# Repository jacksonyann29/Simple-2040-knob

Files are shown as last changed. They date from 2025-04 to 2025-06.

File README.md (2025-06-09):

# Simple-2040-knob
 PCB Design for a single rotary encoder HID, based on a RP2040 microcontroller.

## About
The goal of this project was to get more practice designing PCBs by implementing a microcontroller directly on a PCB. The current iteration successfully works except for USB programming and communication. USB power works, and programming over the SWD pins also works demonstrating that the RP2040 and flash were correctly configured including the crystal oscillator (at least for the simple led blink code tested on the device).

## Future Changes
*	Shorten the USB traces, use a surface mount usb port and double check impedance so USB communication will work.
*	Replace the crystal circuit with an external crystal oscillator IC which would hopefully be simpler to implement and more robust.
*	Add hardware debouncing to the encoder implementation.

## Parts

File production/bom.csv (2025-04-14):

Designator | Footprint | Quantity | Value | LCSC Part #
C1, C2 | 1206 | 2 | 1uF
C10, C9 | 0805 | 2 | 1uF
C11, C12, C15, C3, C4, C5, C6, C7, C8 | 0603 | 9 | 100n
C13 | 0805 | 1 | 29pF
C14 | 0805 | 1 | 27pF
D1 | D_SOD-123F | 1 | MBR1020VL
D2 | 1206 | 1 | LED_25
D3 | 1206 | 1 | PWR
J1 | GCT_USB4085-GF-A_REVB | 1 | USB4085-GF-A_REVB
J2 | PinHeader_1x03_P2.54mm_Vertical | 1 | DEBUG
MT1 | XDCR_PEC11R-4215F-S0024 | 1 | PEC11R-4215F-S0024
R1 | 1206 | 1 | 1M
R10, R7 | 0603 | 2 | 27.4
R11, R4, R5 | 1206 | 3 | 10k
R12, R13, R14, R15 | 1206 | 4 | 1k
R16, R6 | 1206 | 2 | 470
R2, R3 | 1206 | 2 | 5.1k
R8 | 0603 | 1 | DNP
R9 | 0603 | 1 | 1k
SW1 | SW_PUSH_6mm | 1 | BOOT_SEL
TP1 | TestPoint_Pad_D1.5mm | 1 | RUN
TP2 | TestPoint_Pad_D1.5mm | 1 | 1V1
TP3 | TestPoint_Pad_D1.5mm | 1 | 3V3
TP4 | TestPoint_Pad_D1.5mm | 1 | 5V
TP5 | TestPoint_Pad_D1.5mm | 1 | GND
U1 | SOT95P285X140-5N | 1 | AP2112K-3.3TRG1
U2 | QFN40P700X700X90-57N | 1 | SC0914_13_
U3 | SOIC-8_5.23x5.23mm_P1.27mm | 1 | W25Q16JVSS
Y1 | XTAL_ABLS7M-12.000MHZ-B-2-T | 1 | 12MHz

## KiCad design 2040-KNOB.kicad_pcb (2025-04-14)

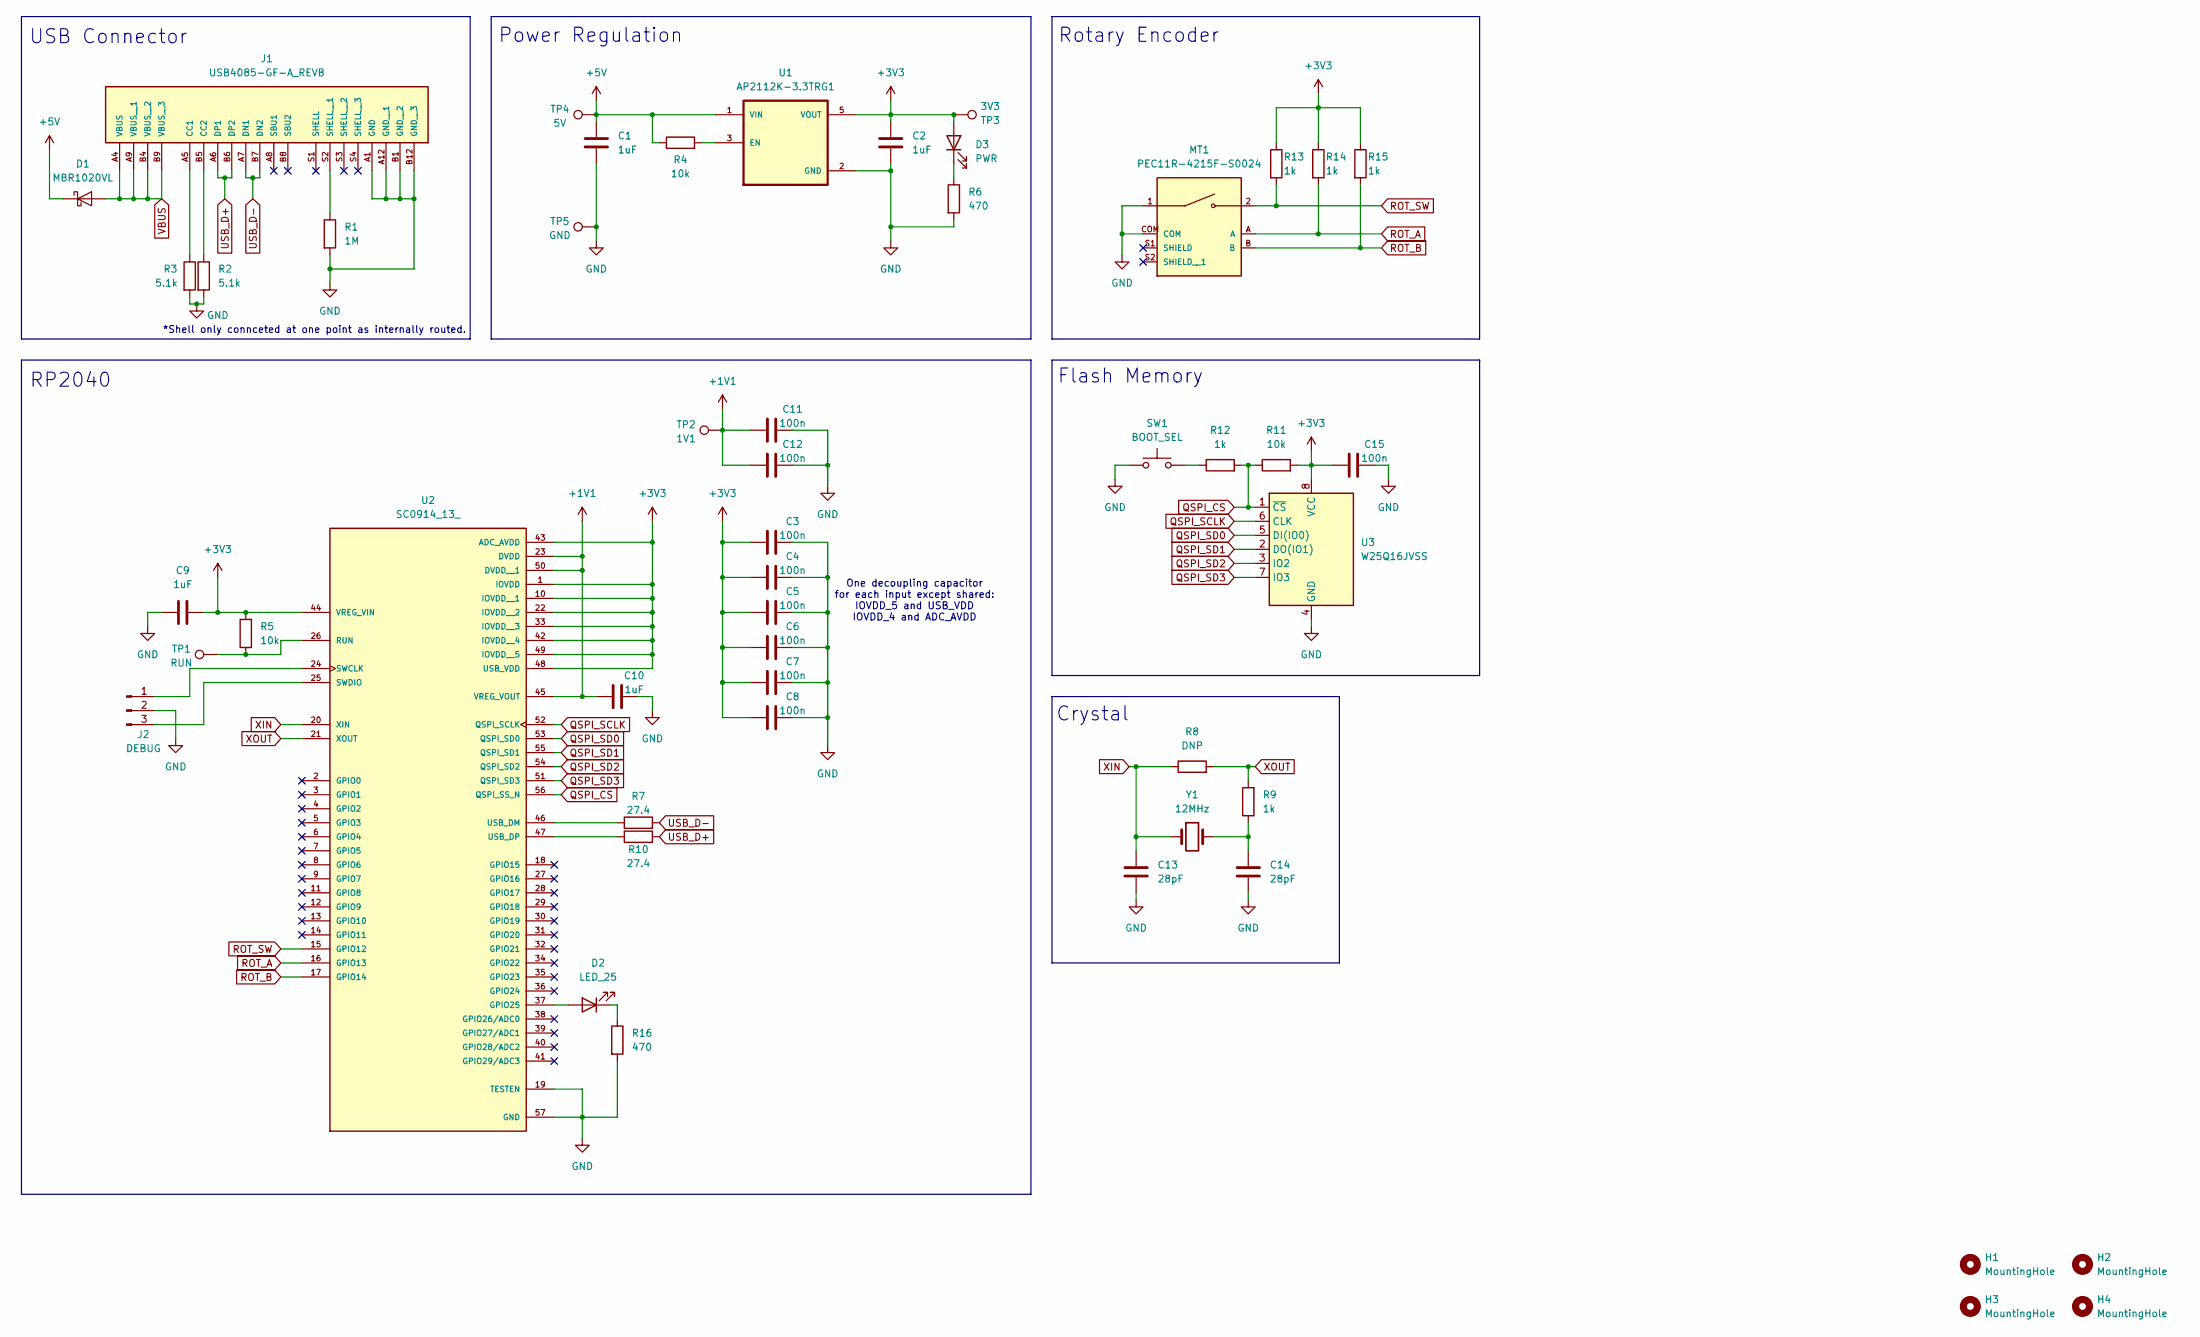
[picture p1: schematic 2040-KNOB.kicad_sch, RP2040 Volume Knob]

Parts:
C1, C2: 1uF; C_1206_3216Metric_Pad1.33x1.80mm_HandSolder
C3, C4, C5, C6, C7, C8, C11, C12, C15: 100n; C_0603_1608Metric_Pad1.08x0.95mm_HandSolder
C9, C10: 1uF; C_0805_2012Metric_Pad1.18x1.45mm_HandSolder
C13, C14: 28pF; C_0805_2012Metric_Pad1.18x1.45mm_HandSolder
D1: MBR1020VL; D_SOD-123F
D2: LED_25; LED_1206_3216Metric_Pad1.42x1.75mm_HandSolder
D3: PWR; LED_1206_3216Metric_Pad1.42x1.75mm_HandSolder
H1, H2, H3, H4: MountingHole; MountingHole_3.2mm_M3_ISO7380_Pad
J1: USB4085-GF-A_REVB; GCT_USB4085-GF-A_REVB; PARTREV B
J2: DEBUG; PinHeader_1x03_P2.54mm_Vertical
MT1: PEC11R-4215F-S0024; XDCR_PEC11R-4215F-S0024; PARTREV Rev. 09/19
R1: 1M; R_1206_3216Metric_Pad1.30x1.75mm_HandSolder
R2, R3: 5.1k; R_1206_3216Metric_Pad1.30x1.75mm_HandSolder
R4, R5, R11: 10k; R_1206_3216Metric_Pad1.30x1.75mm_HandSolder
R6, R16: 470; R_1206_3216Metric_Pad1.30x1.75mm_HandSolder
R7, R10: 27.4; R_0603_1608Metric_Pad0.98x0.95mm_HandSolder
R8: DNP; R_0603_1608Metric_Pad0.98x0.95mm_HandSolder
R9: 1k; R_0603_1608Metric_Pad0.98x0.95mm_HandSolder
R12, R13, R14, R15: 1k; R_1206_3216Metric_Pad1.30x1.75mm_HandSolder
SW1: BOOT_SEL; SW_PUSH_6mm
TP1: RUN; TestPoint_Pad_D1.5mm
TP2: 1V1; TestPoint_Pad_D1.5mm
TP3: 3V3; TestPoint_Pad_D1.5mm
TP4: 5V; TestPoint_Pad_D1.5mm
TP5: GND; TestPoint_Pad_D1.5mm
U1: AP2112K-3.3TRG1; SOT95P285X140-5N; PARTREV 2-2
U2: SC0914_13_; QFN40P700X700X90-57N; PARTREV 2.2
U3: W25Q16JVSS; SOIC-8_5.23x5.23mm_P1.27mm
Y1: 12MHz; XTAL_ABLS7M-12.000MHZ-B-2-T

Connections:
+1V1: C10.2, C11.1, C12.1, TP2.1, U2.23 (DVDD), U2.45 (VREG_VOUT), U2.50 (DVDD__1)
+3V3: C2.1, C3.1, C4.1, C5.1, C6.1, C7.1, C8.1, C9.2, C15.1, D3.2 (A), R5.2, R11.2, R13.1, R14.1, R15.1, TP3.1, U1.5 (VOUT), U2.1 (IOVDD), U2.10 (IOVDD__1), U2.22 (IOVDD__2), U2.33 (IOVDD__3), U2.42 (IOVDD__4), U2.43 (ADC_AVDD), U2.44 (VREG_VIN), U2.48 (USB_VDD), U2.49 (IOVDD__5), U3.8 (VCC)
+5V: C1.1, D1.1 (K), R4.1, TP4.1, U1.1 (VIN)
GND: C1.2, C2.2, C3.2, C4.2, C5.2, C6.2, C7.2, C8.2, C9.1, C10.1, C11.2, C12.2, C13.1, C14.1, C15.2, J1.A1 (GND), J1.A12 (GND__1), J1.B1 (GND__2), J1.B12 (GND__3), J2.2, MT1.1, MT1.COM, R1.2, R2.2, R3.2, R6.2, R16.2, SW1.1, TP5.1, U1.2 (GND), U2.19 (TESTEN), U2.57 (GND), U3.4 (GND)
unnamed: C14.2, R9.1, Y1.2
unnamed: D2.2 (A), U2.37 (GPIO25)
unnamed: D2.1 (K), R16.1
unnamed: D3.1 (K), R6.1
unnamed: J1.A5 (CC1), R3.1
unnamed: J1.B5 (CC2), R2.1
unnamed: J1.S2 (SHELL__1), R1.1
unnamed: J2.1, U2.24 (SWCLK)
unnamed: J2.3, U2.25 (SWDIO)
unnamed: R12.1, SW1.2
unnamed: R4.2, U1.3 (EN)
unnamed: R5.1, TP1.1, U2.26 (RUN)
unnamed: R7.1, U2.46 (USB_DM)
unnamed: R10.1, U2.47 (USB_DP)
QSPI_CS: R11.1, R12.2, U2.56 (QSPI_SS_N), U3.1 (~CS)
QSPI_SCLK: U2.52 (QSPI_SCLK), U3.6 (CLK)
QSPI_SD0: U2.53 (QSPI_SD0), U3.5 (DI(IO0))
QSPI_SD1: U2.55 (QSPI_SD1), U3.2 (DO(IO1))
QSPI_SD2: U2.54 (QSPI_SD2), U3.3 (IO2)
QSPI_SD3: U2.51 (QSPI_SD3), U3.7 (IO3)
ROT_A: MT1.A, R14.2, U2.16 (GPIO13)
ROT_B: MT1.B, R15.2, U2.17 (GPIO14)
ROT_SW: MT1.2, R13.2, U2.15 (GPIO12)
USB_D+: J1.A6 (DP1), J1.B6 (DP2), R10.2
USB_D-: J1.A7 (DN1), J1.B7 (DN2), R7.2
VBUS: D1.2 (A), J1.A4 (VBUS), J1.A9 (VBUS__1), J1.B4 (VBUS__2), J1.B9 (VBUS__3)
XIN: C13.2, R8.1, U2.20 (XIN), Y1.1
XOUT: R8.2, R9.2, U2.21 (XOUT)

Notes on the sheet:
One decoupling capacitor for each input except shared: IOVDD_5 and USB_VDD IOVDD_4 and ADC_AVDD
Rotary Encoder
RP2040
Power Regulation
Flash Memory
USB Connector
*Shell only connceted at one point as internally routed.
Crystal

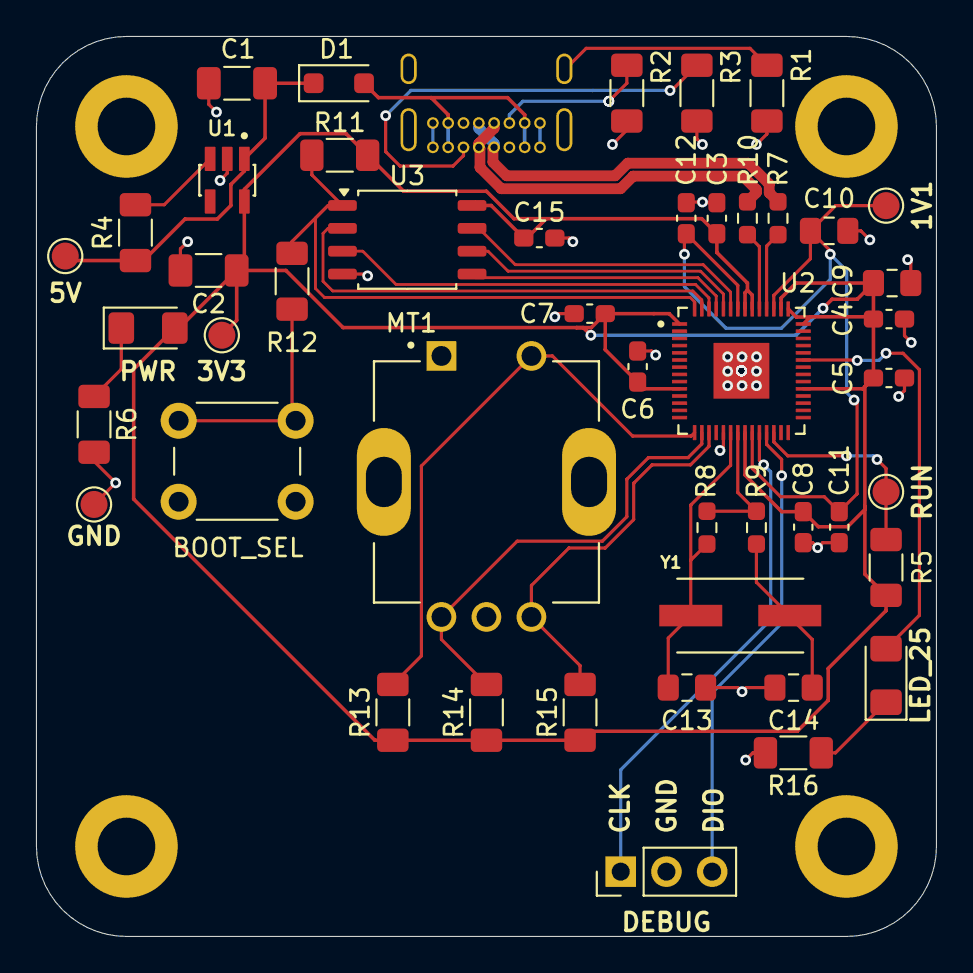
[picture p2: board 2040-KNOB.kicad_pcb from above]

Board: 2 copper layers, 50.0 x 50.0 mm, 51 parts (1 on the bottom side), 32 nets.
